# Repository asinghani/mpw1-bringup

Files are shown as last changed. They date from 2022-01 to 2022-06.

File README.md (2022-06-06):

# mpw1-bringup

Experiments in salvating SKY130 MPW-ONE chips, 1.5 years after the initial tapeout in December 2020.

### Background

MPW-ONE was the first round of the open-source Google-sponsored tapeout, and as a result of tooling issues with the clock-tree verification, the standard "caravel" padframe used for all chips on the MPW contains timing violations. In this repo I am working with my submission to MPW-ONE and attempting to recover functionality using precise voltage and clock control to reduce the significance of these issues - [asinghani/crypto-accelerator-chip](https://github.com/asinghani/crypto-accelerator-chip)

### Board images

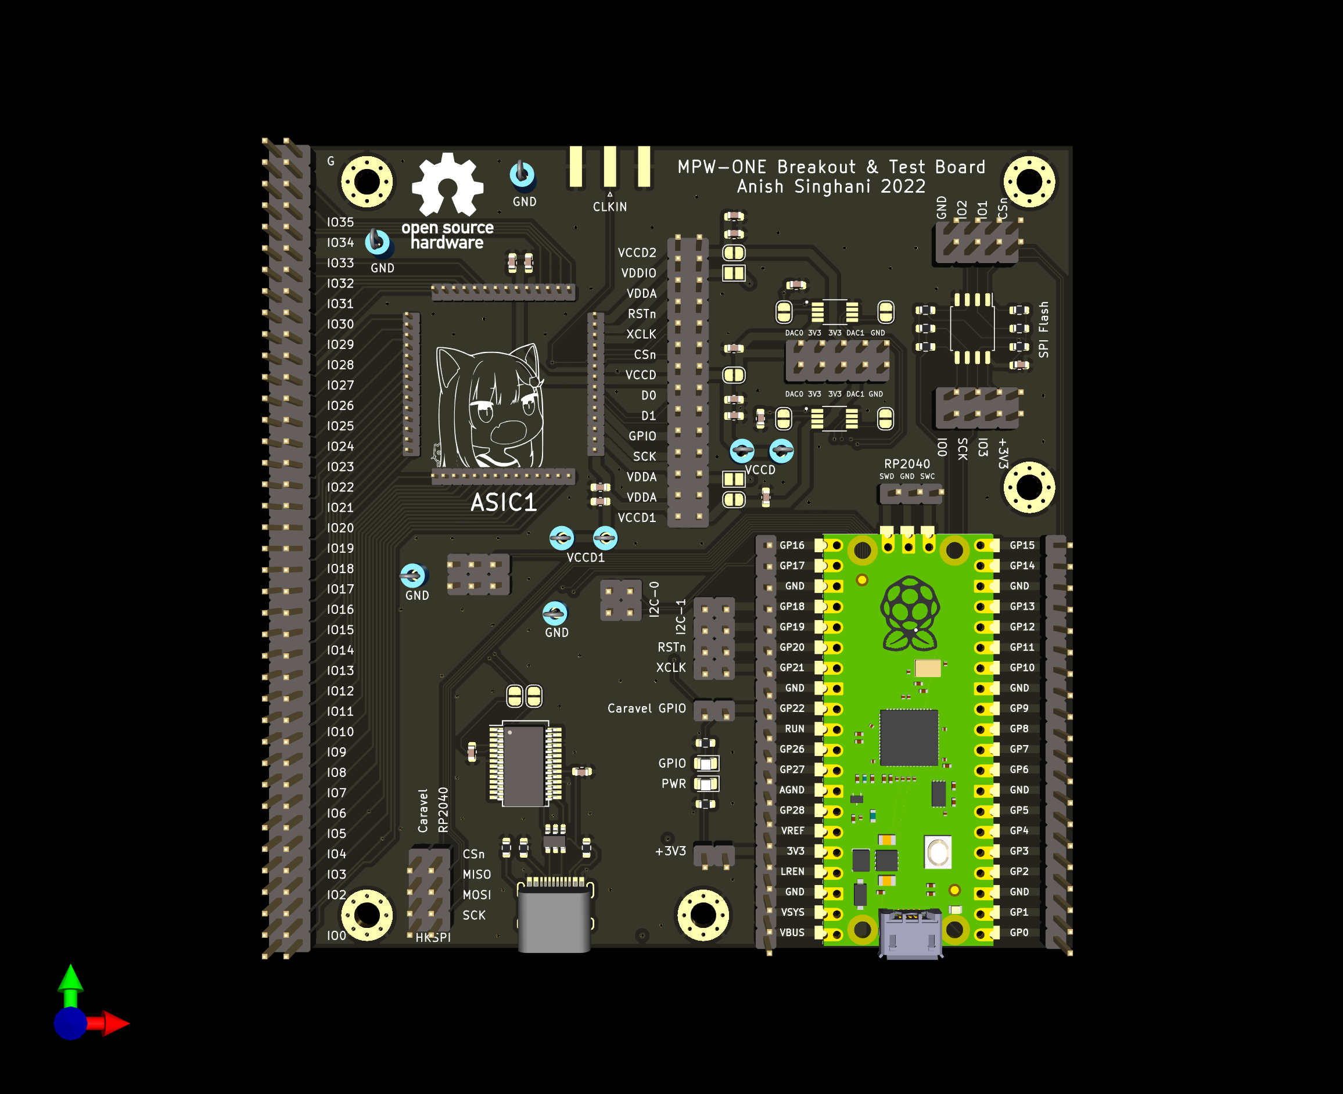
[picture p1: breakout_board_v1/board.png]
board


setup

### Results

- Designed and fabricated a test board (see images above) with a Raspberry Pi Pico and DAC8571
- Implemented firmware (`ctrlfw/remote_ctrl_fw`) and associated Jupyter Notebooks (`notebooks/characterization.ipynb`) for searching possible voltages
- Using this script, tested ~20 dies and found a few that produced sufficient activity on the Flash memory bus
- Implemented a basic communication protocol in RISC-V assembly which allows bytes to be bit-banged (independent of clock frequency) through the single Caravel GPIO port (this means that GPIO do not need to be enabled in order to get data out of the Caravel core
- Used this protocol to read the identifier ROMs that I built in to the SHA256 and AES cores
- Wrote RISC-V code to the Caravel which runs SHA256 on a region of data from flash, and used this to verify the correctness of the SHA256 output (hence proving the correct functionality of the SHA256 core)

identifiers

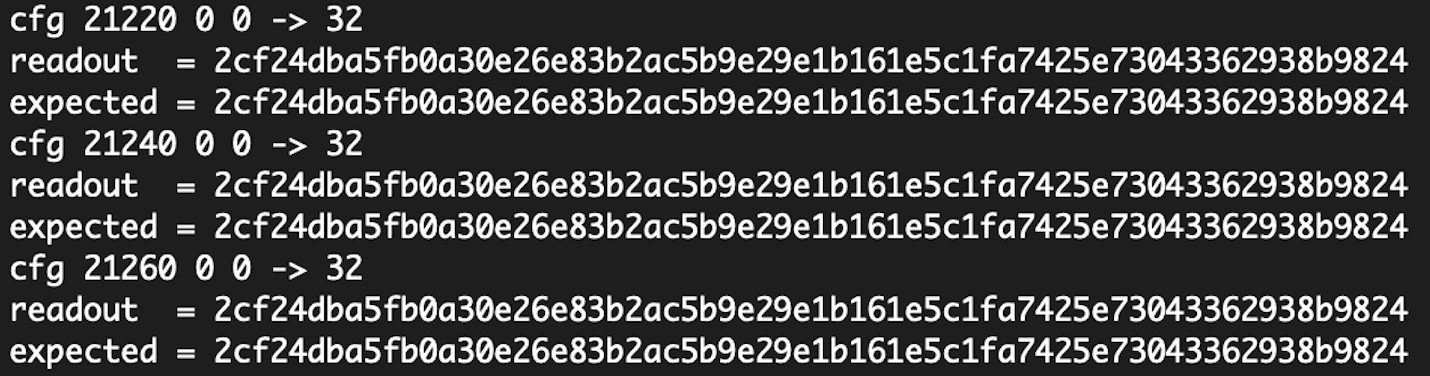
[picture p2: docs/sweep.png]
sweep


The AES core responded to commands but, despite varying the clock frequency, it was not possible to keep clock and power stable enough to get a full successful CBC encryption or decryption. It is likely that there are some dies in the batch where AES will work, but due to the inefficiency in soldering and testing each individual die, I have not tested this yet (I have instead re-submitted an updated version of the AES core to [MPW-THREE](https://github.com/asinghani/crypto-accelerator-chip-v2), using a version of the Caravel padframe does not have the clock-tree issue).

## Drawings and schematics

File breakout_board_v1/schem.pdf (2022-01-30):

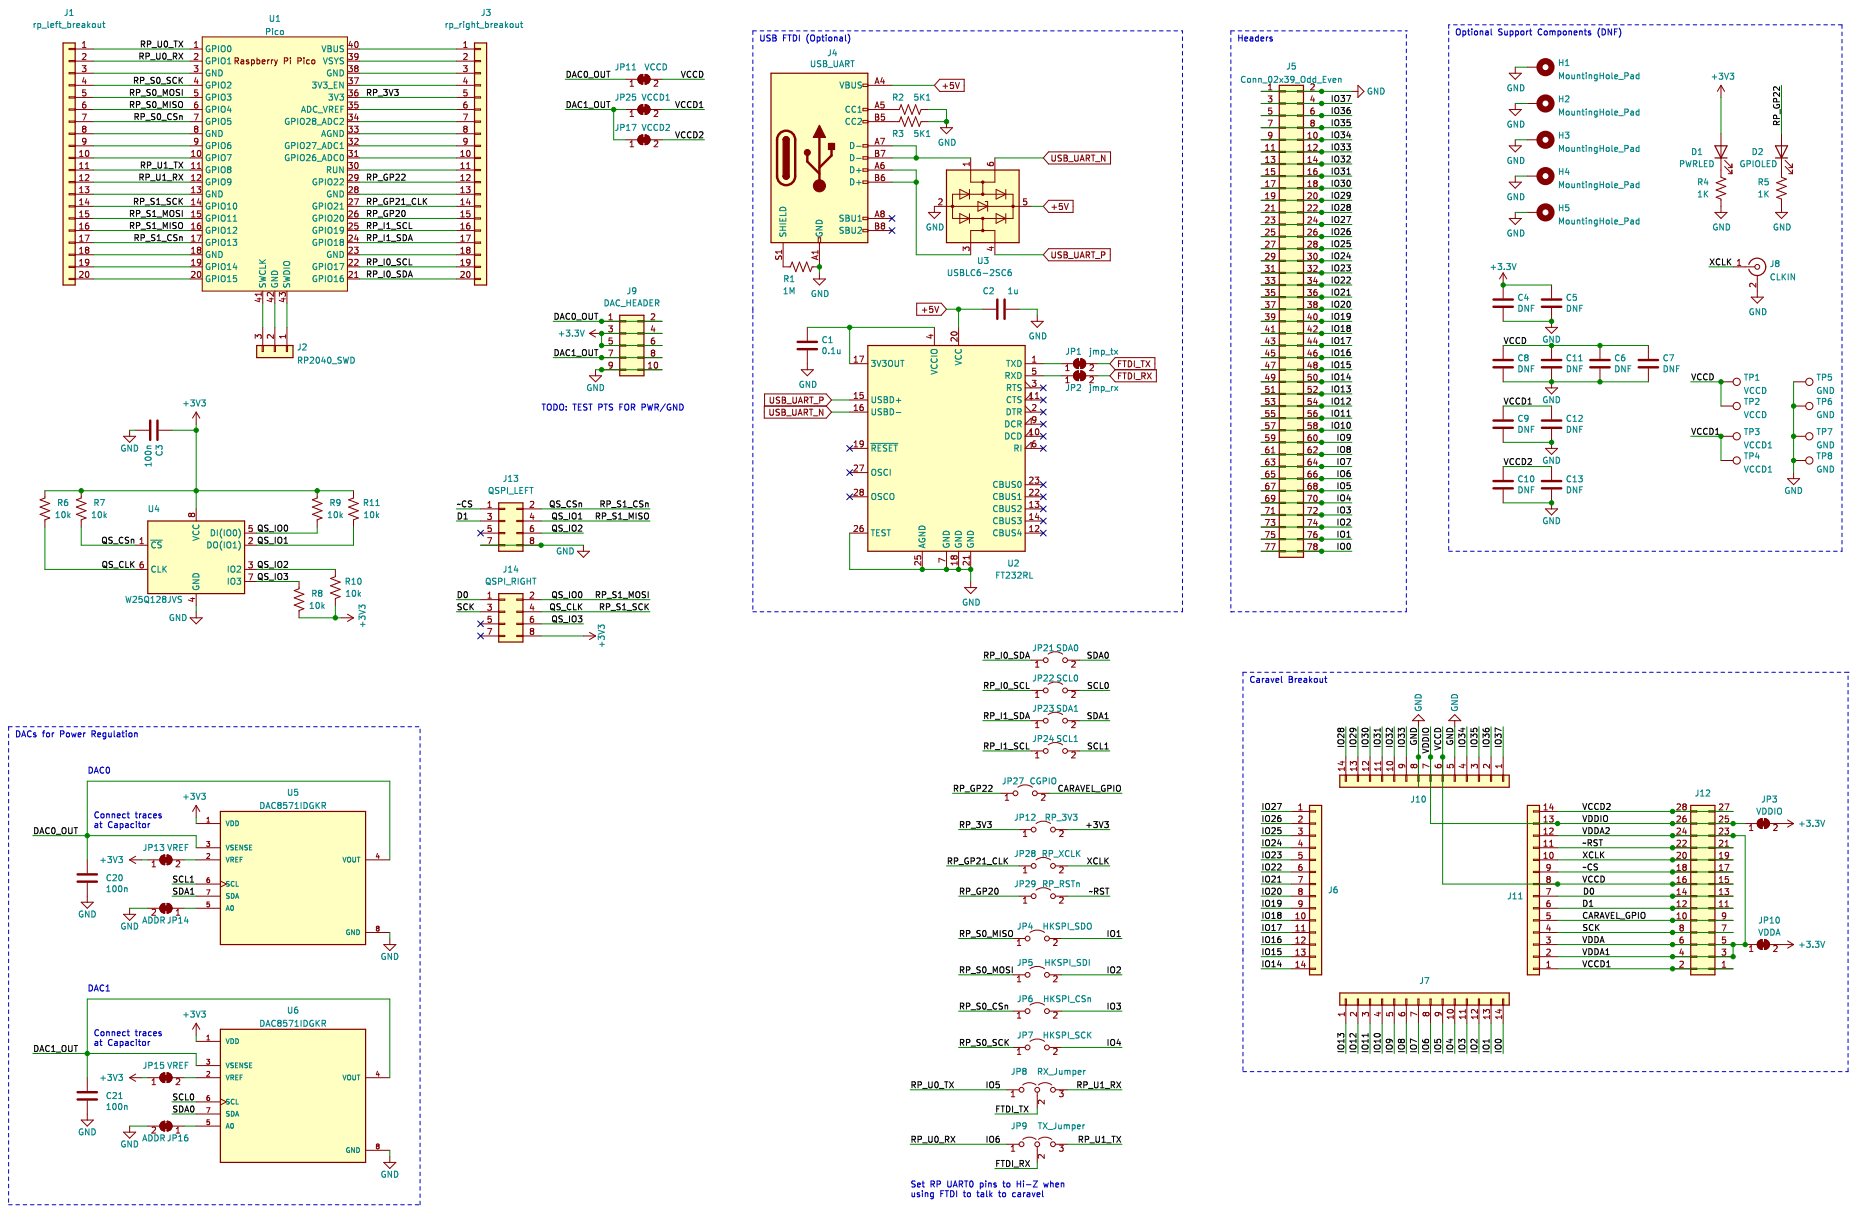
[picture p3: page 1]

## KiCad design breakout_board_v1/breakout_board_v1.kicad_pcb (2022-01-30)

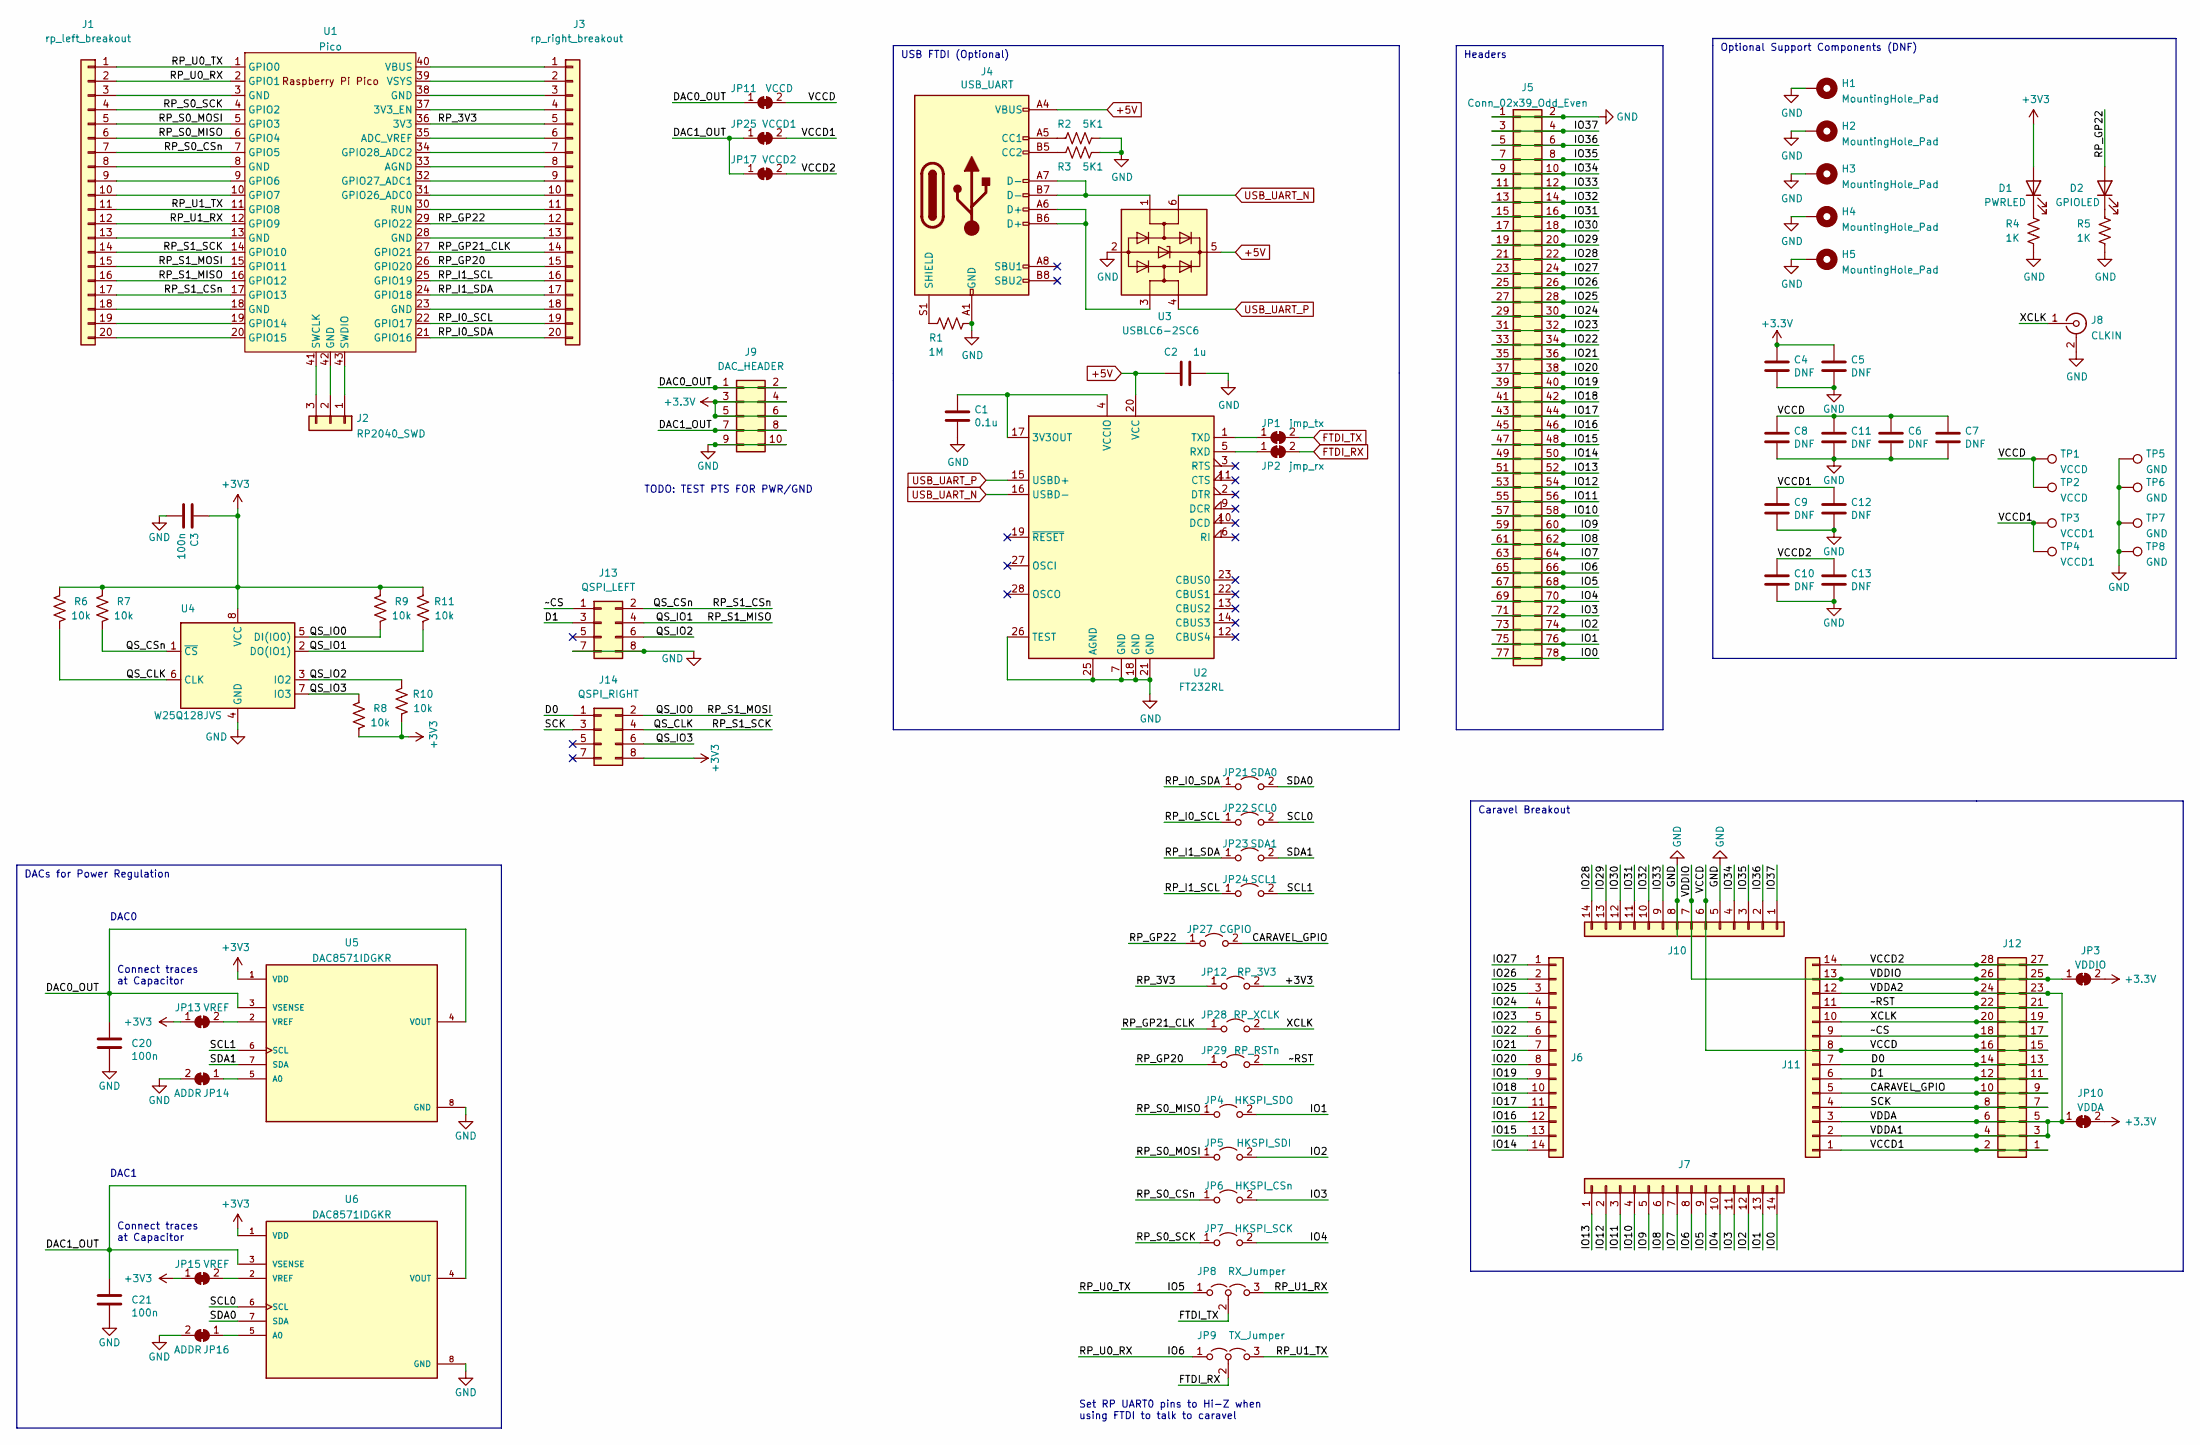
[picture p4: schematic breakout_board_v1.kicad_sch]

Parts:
C1: 0.1u; C_0603_1608Metric
C2: 1u; C_0603_1608Metric
C3, C20, C21: 100n; C_0603_1608Metric
C4, C5, C6, C7, C8, C9, C10, C11, C12, C13: DNF; C_0603_1608Metric
D1: PWRLED; LED_0805_2012Metric
D2: GPIOLED; LED_0805_2012Metric
H1, H2, H3, H4, H5: MountingHole_Pad; MountingHole_3.2mm_M3_Pad_Via
J1: rp_left_breakout; PinHeader_1x20_P2.54mm_Vertical
J2: RP2040_SWD; PinHeader_1x03_P2.54mm_Vertical
J3: rp_right_breakout; PinHeader_1x20_P2.54mm_Vertical
J4: USB_UART; USB_C_Receptacle_HRO_TYPE-C-31-M-12
J5: Conn_02x39_Odd_Even; PinHeader_2x39_P2.54mm_Vertical
J6, J7, J10, J11: Conn_01x14; PinHeader_1x14_P1.27mm_Vertical
J8: CLKIN; SMA_Amphenol_132289_EdgeMount
J9: DAC_HEADER; PinHeader_2x05_P2.54mm_Vertical
J12: Conn_02x14_Odd_Even; PinHeader_2x14_P2.54mm_Vertical
J13: QSPI_LEFT; PinHeader_2x04_P2.54mm_Vertical
J14: QSPI_RIGHT; PinHeader_2x04_P2.54mm_Vertical
JP1: jmp_tx; SolderJumper-2_P1.3mm_Bridged_RoundedPad1.0x1.5mm
JP2: jmp_rx; SolderJumper-2_P1.3mm_Bridged_RoundedPad1.0x1.5mm
JP3: VDDIO; SolderJumper-2_P1.3mm_Bridged2Bar_Pad1.0x1.5mm
JP4: HKSPI_SDO; PinHeader_1x02_P2.54mm_Vertical
JP5: HKSPI_SDI; PinHeader_1x02_P2.54mm_Vertical
JP6: HKSPI_CSn; PinHeader_1x02_P2.54mm_Vertical
JP7: HKSPI_SCK; PinHeader_1x02_P2.54mm_Vertical
JP8: RX_Jumper; PinHeader_1x03_P2.54mm_Vertical
JP9: TX_Jumper; PinHeader_1x03_P2.54mm_Vertical
JP10: VDDA; SolderJumper-2_P1.3mm_Bridged2Bar_Pad1.0x1.5mm
JP11: VCCD; SolderJumper-2_P1.3mm_Bridged2Bar_RoundedPad1.0x1.5mm
JP12: RP_3V3; PinHeader_1x02_P2.54mm_Vertical
JP13, JP15: VREF; SolderJumper-2_P1.3mm_Bridged_RoundedPad1.0x1.5mm
JP14, JP16: ADDR; SolderJumper-2_P1.3mm_Bridged_RoundedPad1.0x1.5mm
JP17: VCCD2; SolderJumper-2_P1.3mm_Bridged2Bar_RoundedPad1.0x1.5mm
JP21: SDA0; PinHeader_1x02_P2.54mm_Vertical
JP22: SCL0; PinHeader_1x02_P2.54mm_Vertical
JP23: SDA1; PinHeader_1x02_P2.54mm_Vertical
JP24: SCL1; PinHeader_1x02_P2.54mm_Vertical
JP25: VCCD1; SolderJumper-2_P1.3mm_Bridged2Bar_RoundedPad1.0x1.5mm
JP27: CGPIO; PinHeader_1x02_P2.54mm_Vertical
JP28: RP_XCLK; PinHeader_1x02_P2.54mm_Vertical
JP29: RP_RSTn; PinHeader_1x02_P2.54mm_Vertical
R1: 1M; R_0603_1608Metric
R2, R3: 5K1; R_0603_1608Metric
R4, R5: 1K; R_0603_1608Metric
R6, R7, R8, R9, R10, R11: 10k; R_0603_1608Metric
TP1, TP2: VCCD; TestPoint_Keystone_5000-5004_Miniature
TP3, TP4: VCCD1; TestPoint_Keystone_5000-5004_Miniature
TP5, TP6, TP7, TP8: GND; TestPoint_Keystone_5000-5004_Miniature
U1: Pico; RPi_Pico_SMD_TH
U2: FT232RL; SSOP-28_5.3x10.2mm_P0.65mm
U3: USBLC6-2SC6; SOT-23-6
U4: W25Q128JVS; SOIC-8_5.23x5.23mm_P1.27mm
U5, U6: DAC8571IDGKR; SOP65P490X110-8N; PARTREV July 2003

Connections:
+5V: C2.1, J4.A4 (VBUS), J4.A9 (VBUS), J4.B4 (VBUS), J4.B9 (VBUS), U2.20 (VCC), U3.5 (VBUS)
/CARAVEL_GPIO: J11.5, J12.9, J12.10, JP27.2 (B)
/D0: J11.7, J12.13, J12.14, J14.1
/D1: J11.6, J12.11, J12.12, J13.3
/DAC0_OUT: C20.1, J9.1, J9.2, JP11.1 (A), U5.3 (VSENSE), U5.4 (VOUT)
/DAC1_OUT: C21.1, J9.7, J9.8, JP17.1 (A), JP25.1 (A), U6.3 (VSENSE), U6.4 (VOUT)
/IO0: J5.77, J5.78, J7.14
/IO1: J5.75, J5.76, J7.13, JP4.2 (B)
/IO2: J5.73, J5.74, J7.12, JP5.2 (B)
/IO3: J5.71, J5.72, J7.11, JP6.2 (B)
/IO4: J5.69, J5.70, J7.10, JP7.2 (B)
/IO5: J1.1, J5.67, J5.68, J7.9, JP8.1 (A), U1.1 (GPIO0)
/IO6: J1.2, J5.65, J5.66, J7.8, JP9.1 (A), U1.2 (GPIO1)
/IO7: J5.63, J5.64, J7.7
/IO8: J5.61, J5.62, J7.6
/IO9: J5.59, J5.60, J7.5
/IO10: J5.57, J5.58, J7.4
/IO11: J5.55, J5.56, J7.3
/IO12: J5.53, J5.54, J7.2
/IO13: J5.51, J5.52, J7.1
/IO14: J5.49, J5.50, J6.14
/IO15: J5.47, J5.48, J6.13
/IO16: J5.45, J5.46, J6.12
/IO17: J5.43, J5.44, J6.11
/IO18: J5.41, J5.42, J6.10
/IO19: J5.39, J5.40, J6.9
/IO20: J5.37, J5.38, J6.8
/IO21: J5.35, J5.36, J6.7
/IO22: J5.33, J5.34, J6.6
/IO23: J5.31, J5.32, J6.5
/IO24: J5.29, J5.30, J6.4
/IO25: J5.27, J5.28, J6.3
/IO26: J5.25, J5.26, J6.2
/IO27: J5.23, J5.24, J6.1
/IO28: J5.21, J5.22, J10.14
/IO29: J5.19, J5.20, J10.13
/IO30: J5.17, J5.18, J10.12
/IO31: J5.15, J5.16, J10.11
/IO32: J5.13, J5.14, J10.10
/IO33: J5.11, J5.12, J10.9
/IO34: J5.9, J5.10, J10.4
/IO35: J5.7, J5.8, J10.3
/IO36: J5.5, J5.6, J10.2
/IO37: J5.3, J5.4, J10.1
/QS_CLK: J1.14, J14.4, R6.2, U1.14 (GPIO10), U4.6 (CLK)
/QS_CSn: J1.17, J13.2, R7.2, U1.17 (GPIO13), U4.1 (~CS)
/QS_IO0: J1.15, J14.2, R9.2, U1.15 (GPIO11), U4.5 (DI(IO0))
/QS_IO1: J1.16, J13.4, R11.2, U1.16 (GPIO12), U4.2 (DO(IO1))
/QS_IO2: J13.6, R10.1, U4.3 (IO2)
/QS_IO3: J14.6, R8.1, U4.7 (IO3)
/RP_3V3: J3.5, JP12.1 (A), U1.36 (3V3)
/RP_GP20: J3.15, JP29.1 (A), U1.26 (GPIO20)
/RP_GP21_CLK: J3.14, JP28.1 (A), U1.27 (GPIO21)
/RP_GP22: D2.2 (A), J3.12, JP27.1 (A), U1.29 (GPIO22)
/RP_I0_SCL: J3.19, JP22.1 (A), U1.22 (GPIO17)
/RP_I0_SDA: J3.20, JP21.1 (A), U1.21 (GPIO16)
/RP_I1_SCL: J3.16, JP24.1 (A), U1.25 (GPIO19)
/RP_I1_SDA: J3.17, JP23.1 (A), U1.24 (GPIO18)
/RP_S0_CSn: J1.7, JP6.1 (A), U1.7 (GPIO5)
/RP_S0_MISO: J1.6, JP4.1 (A), U1.6 (GPIO4)
/RP_S0_MOSI: J1.5, JP5.1 (A), U1.5 (GPIO3)
/RP_S0_SCK: J1.4, JP7.1 (A), U1.4 (GPIO2)
/RP_U1_RX: J1.12, JP8.3 (B), U1.12 (GPIO9)
/RP_U1_TX: J1.11, JP9.3 (B), U1.11 (GPIO8)
/SCK: J11.4, J12.7, J12.8, J14.3
/SCL0: JP22.2 (B), U6.6 (SCL)
/SCL1: JP24.2 (B), U5.6 (SCL)
/SDA0: JP21.2 (B), U6.7 (SDA)
/SDA1: JP23.2 (B), U5.7 (SDA)
/VCCD: C6.1, C7.1, C8.1, C11.1, J10.6, J11.8, J12.15, J12.16, JP11.2 (B), TP1.1, TP2.1
/VCCD1: C9.1, C12.1, J11.1, J12.1, J12.2, JP25.2 (B), TP3.1, TP4.1
/VCCD2: C10.1, C13.1, J11.14, J12.27, J12.28, JP17.2 (B)
/VDDA: J11.2, J11.3, J11.12, J12.3, J12.4, J12.5, J12.6, J12.23, J12.24, JP10.1 (A)
/VDDIO: J10.7, J11.13, J12.25, J12.26, JP3.1 (A)
/XCLK: J8.1 (In), J11.10, J12.19, J12.20, JP28.2 (B)
/~CS: J11.9, J12.17, J12.18, J13.1
/~RST: J11.11, J12.21, J12.22, JP29.2 (B)
FTDI_RX: JP2.2 (B), JP9.2 (C)
FTDI_TX: JP1.2 (B), JP8.2 (C)
GND: C1.2, C2.2, C3.2, C4.2, C5.2, C6.2, C7.2, C8.2, C9.2, C10.2, C11.2, C12.2, C13.2, C20.2, C21.2, H1.1, H2.1, H3.1, H4.1, H5.1, J4.A1 (GND), J4.A12 (GND), J4.B1 (GND), J4.B12 (GND), J5.1, J5.2, J8.2 (Ext), J9.9, J9.10, J10.5, J10.8, J13.7, J13.8, JP14.2 (B), JP16.2 (B), R1.2, R2.2, R3.2, R4.2, R5.2, TP5.1, TP6.1, TP7.1, TP8.1, U2.7 (GND), U2.18 (GND), U2.21 (GND), U2.25 (AGND), U2.26 (TEST), U3.2 (GND), U4.4 (GND), U5.8 (GND), U6.8 (GND)
unnamed: C1.1, U2.4 (VCCIO), U2.17 (3V3OUT)
unnamed: D1.1 (K), R4.1
unnamed: D2.1 (K), R5.1
unnamed: J1.3, U1.3 (GND)
unnamed: J1.8, U1.8 (GND)
unnamed: J1.9, U1.9 (GPIO6)
unnamed: J1.10, U1.10 (GPIO7)
unnamed: J1.13, U1.13 (GND)
unnamed: J1.18, U1.18 (GND)
unnamed: J1.19, U1.19 (GPIO14)
unnamed: J1.20, U1.20 (GPIO15)
unnamed: J2.1, U1.43 (SWDIO)
unnamed: J2.2, U1.42 (GND)
unnamed: J2.3, U1.41 (SWCLK)
unnamed: J3.1, U1.40 (VBUS)
unnamed: J3.2, U1.39 (VSYS)
unnamed: J3.3, U1.38 (GND)
unnamed: J3.4, U1.37 (3V3_EN)
unnamed: J3.6, U1.35 (ADC_VREF)
unnamed: J3.7, U1.34 (GPIO28_ADC2)
unnamed: J3.8, U1.33 (AGND)
unnamed: J3.9, U1.32 (GPIO27_ADC1)
unnamed: J3.10, U1.31 (GPIO26_ADC0)
unnamed: J3.11, U1.30 (RUN)
unnamed: J3.13, U1.28 (GND)
unnamed: J3.18, U1.23 (GND)
unnamed: J4.A5 (CC1), R2.1
unnamed: J4.A6 (D+), J4.B6 (D+), U3.3 (I/O2)
unnamed: J4.A7 (D-), J4.B7 (D-), U3.1 (I/O1)
unnamed: J4.B5 (CC2), R3.1
unnamed: J4.S1 (SHIELD), R1.1
unnamed: JP1.1 (A), U2.1 (TXD)
unnamed: JP2.1 (A), U2.5 (RXD)
unnamed: JP13.2 (B), U5.2 (VREF)
unnamed: JP14.1 (A), U5.5 (A0)
unnamed: JP15.2 (B), U6.2 (VREF)
unnamed: JP16.1 (A), U6.5 (A0)
USB_UART_N: U2.16 (USBD-), U3.6 (I/O1)
USB_UART_P: U2.15 (USBD+), U3.4 (I/O2)

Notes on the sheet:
Set RP UART0 pins to Hi-Z when using FTDI to talk to caravel
DAC0
DACs for Power Regulation
USB FTDI (Optional)
Optional Support Components (DNF)
Caravel Breakout
TODO: TEST PTS FOR PWR/GND
DAC1
Connect traces at Capacitor
Headers

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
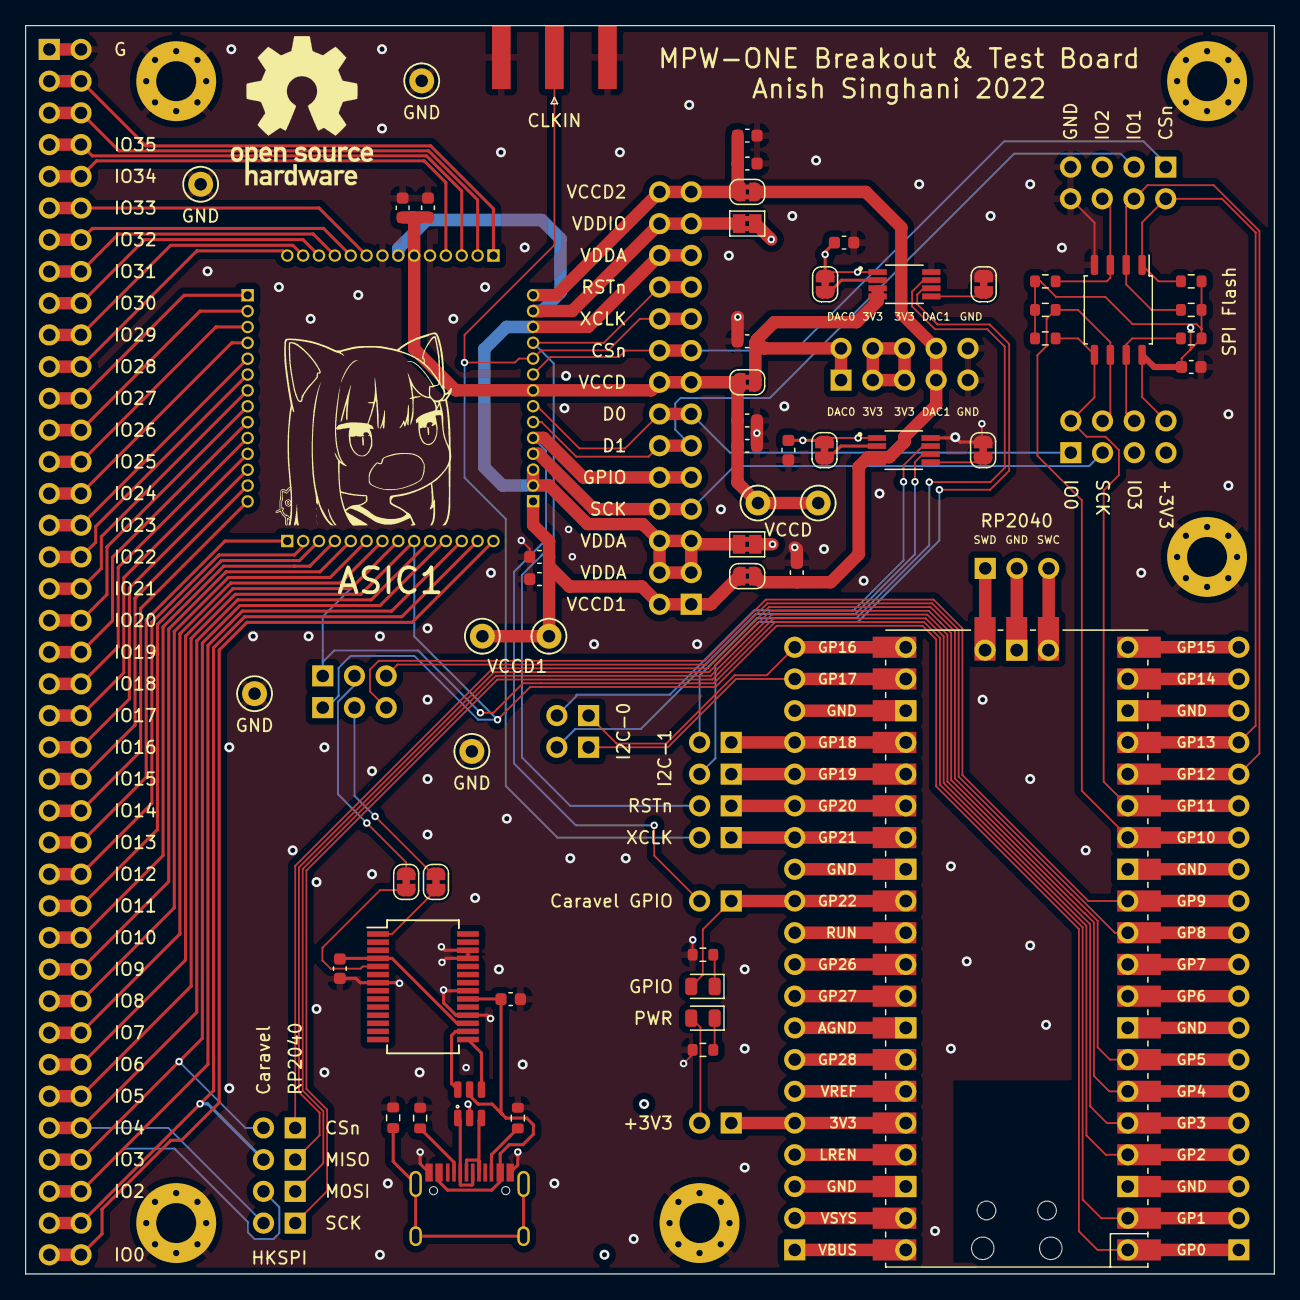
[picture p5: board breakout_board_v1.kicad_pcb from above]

Board: 4 copper layers, 100.0 x 100.0 mm, 86 parts (0 on the bottom side), 120 nets.

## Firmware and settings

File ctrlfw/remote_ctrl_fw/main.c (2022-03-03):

#include <stdio.h>
#include "pico/stdlib.h"
#include "hardware/i2c.h"
#include "hardware/clocks.h"

#include "config.h"
#include "dac.h"
#include "datachannel.h"
#include "spiflash.h"

// Chip-select transition counter
uint32_t cs_ctr = 0;
void reset_ctr() { cs_ctr = 0; }

// GPIO interrupt
void gpio_int(unsigned int gpio, uint32_t events) {
    if ((gpio == FLASH_CS_PIN)) {
        cs_ctr++;
    } else if (gpio == CARAVEL_GPIO_PIN) {
        if (events & 0x8) dc_int_rose();
        else if (events & 0x4) dc_int_fell();
    }
}

void setup() {
    //stdio_uart_init_full(uart1, 115200, 8, 9);
    stdio_usb_init();

    init_dac_i2c();

    gpio_init(RSTn_PIN);
    gpio_set_dir(RSTn_PIN, true); // output

    gpio_init(FLASH_CS_PIN);
    gpio_set_dir(FLASH_CS_PIN, false); // input

    gpio_init(CARAVEL_GPIO_PIN);
    gpio_set_dir(CARAVEL_GPIO_PIN, false); // input

    // Enable IRQs
    gpio_set_irq_enabled_with_callback(CARAVEL_GPIO_PIN, GPIO_IRQ_EDGE_RISE | GPIO_IRQ_EDGE_FALL, true, &gpio_int);
    gpio_set_irq_enabled_with_callback(FLASH_CS_PIN, GPIO_IRQ_EDGE_RISE | GPIO_IRQ_EDGE_FALL, true, &gpio_int);

    init_dac_caravel();
    init_dac_proj();
}

void set_clkdiv(uint32_t div) {
    // Starts with the 48MHz USB clock and divides down
    clock_gpio_init(XCLK_PIN, CLOCKS_CLK_GPOUT0_CTRL_AUXSRC_VALUE_CLK_USB, div);
}

int main() {
    sleep_ms(500);
    
    // Configure and set things to sane defaults
    setup();
    set_clkdiv(12); // 4MHz
    set_voltage_caravel(20000);
    set_voltage_proj(20000);

    flash_init();
    flash_deinit();

    sleep_ms(500);

    // Pull chip into reset
    gpio_put(RSTn_PIN, 0);

    // Remote command interface
    while (true) {
        int x = getchar_timeout_us(1000000);
        if (x < 0 || x > 255) continue;

        char cmd = (char) x;
        switch (cmd) {
            case 'R': {
                // Reset (R0/R1)
                int x = getchar_timeout_us(1000000);
                if (x == (int) '0') {
                    gpio_put(RSTn_PIN, 1); // Not-reset
                    putchar_raw('S');

                } else if (x == (int) '1') {
                    gpio_put(RSTn_PIN, 0); // Reset
                    putchar_raw('S');

                } else {
                    putchar_raw('?');
                }
                break;
            }

            case 'T': {
                // Enable for given number of millis, then back into reset
                // (lower-latency than sending two reset commands)

                uint32_t t = 0;
                t |= (getchar_timeout_us(1000000) & 0xFF);
                t |= (getchar_timeout_us(1000000) & 0xFF) << 8;
                t |= (getchar_timeout_us(1000000) & 0xFF) << 16;
                t |= (getchar_timeout_us(1000000) & 0xFF) << 24;

                if (t > 20000) {
                    putchar_raw('?');
                    break;
                }

                putchar_raw('A');

                gpio_put(RSTn_PIN, 0); // Reset
                sleep_ms(10);
                gpio_put(RSTn_PIN, 1); // Not-reset
                sleep_ms(t);
                gpio_put(RSTn_PIN, 0); // Reset

                putchar_raw('S');

                break;
            }

            case 'C': {
                // Set clk div
                int a = getchar_timeout_us(1000000);
                int b = getchar_timeout_us(1000000);
                uint16_t d = ((b & 0xFF) << 8) | (a & 0xFF);

                set_clkdiv(d);
                putchar_raw('S');
                break;
            }

            case 'V': {
                // Set caravel voltage
                int a = getchar_timeout_us(1000000);
                int b = getchar_timeout_us(1000000);
                uint16_t d = ((b & 0xFF) << 8) | (a & 0xFF);

                set_voltage_caravel(d);
                putchar_raw('S');
                break;
            }

            case 'P': {
                // Set project voltage
                int a = getchar_timeout_us(1000000);
                int b = getchar_timeout_us(1000000);
                uint16_t d = ((b & 0xFF) << 8) | (a & 0xFF);

                set_voltage_proj(d);
                putchar_raw('S');
                break;
            }

            case 'E': {
                // Reset counter
                reset_ctr();
                putchar_raw('S');
                break;
            }

            case 'W': {
                // Read counter
                uint32_t c = cs_ctr;
                putchar_raw('S');
                putchar_raw(c & 0xFF);
                putchar_raw((c >> 8) & 0xFF);
                putchar_raw((c >> 16) & 0xFF);
                putchar_raw((c >> 24) & 0xFF);
                break;
            }

            case 'I': {
                // Reset datachannel
                dc_reset();
                putchar_raw('S');
                break;
            }

            case 'O': {
                // Read datachannel buffer length
                uint32_t c = dc_get_len();
                putchar_raw('S');
                putchar_raw(c & 0xFF);
                putchar_raw((c >> 8) & 0xFF);
                putchar_raw((c >> 16) & 0xFF);
                putchar_raw((c >> 24) & 0xFF);
                break;
            }

            case 'U': {
                // Read datachannel buffer
                uint32_t c = dc_get_len();
                putchar_raw('S');
                putchar_raw(c & 0xFF);
                putchar_raw((c >> 8) & 0xFF);
                putchar_raw((c >> 16) & 0xFF);
                putchar_raw((c >> 24) & 0xFF);

                for (uint32_t i = 0; i < c; i++) {
                    putchar_raw(dc_buf[i]);
                }
                break;
            }

            case 'J': {
                // Read flash
                uint32_t addr = 0;
                addr |= (getchar_timeout_us(1000000) & 0xFF);
                addr |= (getchar_timeout_us(1000000) & 0xFF) << 8;
                addr |= (getchar_timeout_us(1000000) & 0xFF) << 16;
                addr |= (getchar_timeout_us(1000000) & 0xFF) << 24;

                uint32_t len = 0;
                len |= (getchar_timeout_us(1000000) & 0xFF);
                len |= (getchar_timeout_us(1000000) & 0xFF) << 8;
                len |= (getchar_timeout_us(1000000) & 0xFF) << 16;
                len |= (getchar_timeout_us(1000000) & 0xFF) << 24;

                if (len > 65535) {
                    putchar_raw('?');
                    break;
                } else {
                    char buf[len];

                    // Reset caravel before accessing flash
                    gpio_put(RSTn_PIN, 0);
                    flash_init();
                    flash_read(addr, buf, len);
                    flash_deinit();

                    putchar_raw('S');
                    for (uint32_t i = 0; i < len; i++) {
                        putchar_raw(buf[i]);
                    }
                }
                
                break;
            }

            case 'K': {
                // Write flash
                uint32_t addr = 0;
                addr |= (getchar_timeout_us(1000000) & 0xFF);
                addr |= (getchar_timeout_us(1000000) & 0xFF) << 8;
                addr |= (getchar_timeout_us(1000000) & 0xFF) << 16;
                addr |= (getchar_timeout_us(1000000) & 0xFF) << 24;

                char buf[4096];

                for (int i = 0; i < 4096; i++) {
                    buf[i] = getchar_timeout_us(1000000) & 0xFF;
                }

                putchar_raw('A');

                // Reset caravel before accessing flash
                gpio_put(RSTn_PIN, 0);
                flash_init();
                int res = flash_write_sector(addr, buf);
                int res2 = flash_verify_sector(addr, buf);
                flash_deinit();

                if (res == 0 && res2 == 0) putchar_raw('S');
                else putchar_raw('X');
                
                break;
            }

            default: {
                putchar_raw('?');
                break;
            }
        }
    }

    while (1);
    return 0;
}

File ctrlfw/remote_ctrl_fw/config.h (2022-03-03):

#define RSTn_PIN 20
#define XCLK_PIN 21

#define FLASH_SPI spi1
#define FLASH_SCK_PIN 10
#define FLASH_MOSI_PIN 11
#define FLASH_MISO_PIN 12
#define FLASH_CS_PIN 13

#define CARAVEL_GPIO_PIN 22

#define I2C0_SDA 16
#define I2C0_SCL 17

#define I2C1_SDA 18
#define I2C1_SCL 19

#define DAC_CARAVEL_BUS i2c1
#define DAC_CARAVEL_ADDR 0x4C

#define DAC_PROJ_BUS i2c0
#define DAC_PROJ_ADDR 0x4C

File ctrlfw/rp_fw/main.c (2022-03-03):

#include <stdio.h>
#include "pico/stdlib.h"
#include "hardware/i2c.h"
#include "config.h"
#include "dac.h"
#include "hardware/clocks.h"

uint32_t ctr = 0;
void reset_ctr() { ctr = 0; }

void run_sweep() {
    // Sweep
    //for (uint16_t i = 20500; i < 21200; i += 5) {
    for (uint16_t i = 13500; i < 26000; i += 40) {
        gpio_put(RSTn_PIN, 0);
        sleep_ms(10);
        reset_ctr();
        printf("cfg %d %d %d -> ", i, set_voltage_caravel(i), set_voltage_proj(i));
        gpio_put(RSTn_PIN, 1);
        sleep_ms(20);
        //gpio_put(RSTn_PIN, 0);
        printf("%d\n", ctr);
    }
}

int run_repeated_tests(int repeats) {
    int successes = 0;
    for (int x = 0; x < repeats; x++) {
        gpio_put(RSTn_PIN, 0);
        reset_ctr();
        gpio_put(RSTn_PIN, 1);
        sleep_ms(30);
        gpio_put(RSTn_PIN, 0);
        if (ctr > 1200 && ctr < 1400) successes++;
        sleep_ms(30);
    }

    return successes;
}

void run_repeated() {
    int repeats = 20;

    // Sweep
    for (uint16_t i = 20500; i < 21200; i += 10) {
        printf("cfg %d %d %d -> ", i, set_voltage_caravel(i), set_voltage_proj(i));
        int successes = run_repeated_tests(repeats);
        printf("%d\n", successes);
    }
}

char outputbuf[256];
uint8_t cur_char = 0;
int bit_ctr = 0;
int char_ctr = 0;
uint64_t risetime = 0;

void reset_outputbuf() {
    cur_char = 0;
    bit_ctr = 0;
    char_ctr = 0;
    risetime = 0;
}

void caravel_gpio(unsigned int gpio, uint32_t events) {
    if ((gpio == FLASH_CS_PIN)) {
        ctr++;

    } else if (gpio == CARAVEL_GPIO_PIN) {

        if (events & 0x8) { // Rise
            risetime = time_us_64();

        } else if (events & 0x4) {
            uint64_t time = time_us_64() - risetime;

            if (time > 500) {
                cur_char |= (0x1 << bit_ctr);
            }

            bit_ctr += 1;
            if (bit_ctr == 8) {
                bit_ctr = 0;
                outputbuf[char_ctr] = cur_char;
                char_ctr += 1;
                cur_char = 0;
            }
        }

    }
}

void hexprintln(char *buf, int length) {
    for (int i = 0; i < length; i++) {
        printf("%02x", buf[i]);
    }
    printf("\n");
}

void run_sweep2() {
    // Sweep
    //for (uint16_t i = 20500; i < 21200; i += 5) {
    //for (uint16_t i = 19000; i < 22000; i += 10) {
    for (uint16_t i = 16700; i < 22900; i += 200) {
        gpio_put(RSTn_PIN, 0);
        sleep_ms(10);
        reset_ctr();
        printf("cfg %d %d %d -> ", i, set_voltage_caravel(20500), set_voltage_proj(i));
        reset_outputbuf();
        gpio_put(RSTn_PIN, 1);
        sleep_ms(500);
        //gpio_put(RSTn_PIN, 0);
        outputbuf[char_ctr] = 0;
        //printf("readout %s\n", outputbuf);
        printf("%d %d\n", ctr, char_ctr);
        printf("readout  = ");
        //hexprintln(outputbuf, 16);
        hexprintln(outputbuf, 32);
        printf("expected = 41812dc60561798dc0cc6e574b641893ecf4186d4097283af4a6cff3eddaa4a0\n");
    }
}

int main() {
    stdio_usb_init();
    stdio_uart_init_full(uart1, 115200, 8, 9);

    printf("Gmorn\n");
    sleep_ms(1000);

    printf("SWEEP\n");

    init_dac_i2c();

    gpio_init(RSTn_PIN);
    gpio_set_dir(RSTn_PIN, true); // output

    gpio_init(FLASH_CS_PIN);
    gpio_set_dir(FLASH_CS_PIN, false); // input
    //gpio_set_irq_enabled_with_callback(FLASH_CS_PIN, GPIO_IRQ_EDGE_FALL, true, &ctr_interrupt);

    gpio_init(CARAVEL_GPIO_PIN);
    gpio_set_dir(CARAVEL_GPIO_PIN, false); // input

    // apparently this handles all IRQs
    gpio_set_irq_enabled_with_callback(CARAVEL_GPIO_PIN, GPIO_IRQ_EDGE_RISE | GPIO_IRQ_EDGE_FALL, true, &caravel_gpio);
    gpio_set_irq_enabled_with_callback(FLASH_CS_PIN, GPIO_IRQ_EDGE_RISE | GPIO_IRQ_EDGE_FALL, true, &caravel_gpio);

    // clock output 500khz
    clock_gpio_init(XCLK_PIN, CLOCKS_CLK_GPOUT0_CTRL_AUXSRC_VALUE_CLK_USB, 12);

    printf("Setup Caravel DAC %d\n", init_dac_caravel());
    printf("Setup Project DAC %d\n", init_dac_proj());
    sleep_ms(500);

    //printf("cfg %d %d %d -> ", 21050, set_voltage_caravel(21050), set_voltage_proj(21050));
    //int successes = run_repeated_tests(100);
    //printf("%d\n", successes);

    run_sweep2();
    //run_sweep();

    gpio_put(RSTn_PIN, 0);
    //run_repeated();

    while (1);

    return 0;
}
